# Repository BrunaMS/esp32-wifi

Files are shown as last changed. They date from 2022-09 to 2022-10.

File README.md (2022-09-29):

# esp32-wifi
In this project I'm using ESP32 with ESP-IDF framework to implement an Wi-Fi connection, allowing to download 500kb files from a device at least 100m away

## Firmware
### Environment
To develop and build this firmware I'm using VSCode and it's extensions. The main extension required to build it is platformIO but others like git extension can be used to help with version control and gitflow. 

### Task routine
To work with different services/threads I chose to use the  

## Hardware
For now, I'm using KiCad 6.0 to create schematics and PCB for this project. During the development was necessary to download components from external sources. These are:
- Example I
- Example II

### Components 
For this project some circuits are necessary, mainly to guarantee battery charging and to protect other modules and the microcontroller from damages.
- BQ - Battery control
- USB Protection circuit
- Crystal
- Voltage regulator
- Wi-Fi antenna performance
- GPIOs

### Microcontroller
The chosen microcontroller for this application was the ESP32-WROOM, developed to work with IoT and wireless in general, making wireless communication protocols easier to develop and use.

### Routing
The general rules for the routing process were:
1. Consider one manufacturer to define the correct pcb specifications (hole size, clearance, board thickness, impedance control, etc)
2. Always consider grounding rules
3. Avoid interference from power lines
4. Avoid keep high-speed signals close to other signals

## TODO 

|Area | Type |Description|
|-----|---|---|
|Firmware|Feature|Move device mode selector from kconfig to serial/nvs memory
|Firmware|Feature|Develop some type of interface to be used when it is in receiver mode
|Firmware|Fix| Convert components into real components (submodules in git), making possible the use in other projects
|Firmware|Fix| Organize the different "layers" of the project (e.g. components, common, task, main), creating uncoupled classes/libraries/functions
|Firmware|Docs| Explain function in header (.h file) of each component(brief, params, return) using Doxygen 
|Hardware|Test|Check if with built-in antenna can reach 100m of distance between devices or if its necessary to use another one |

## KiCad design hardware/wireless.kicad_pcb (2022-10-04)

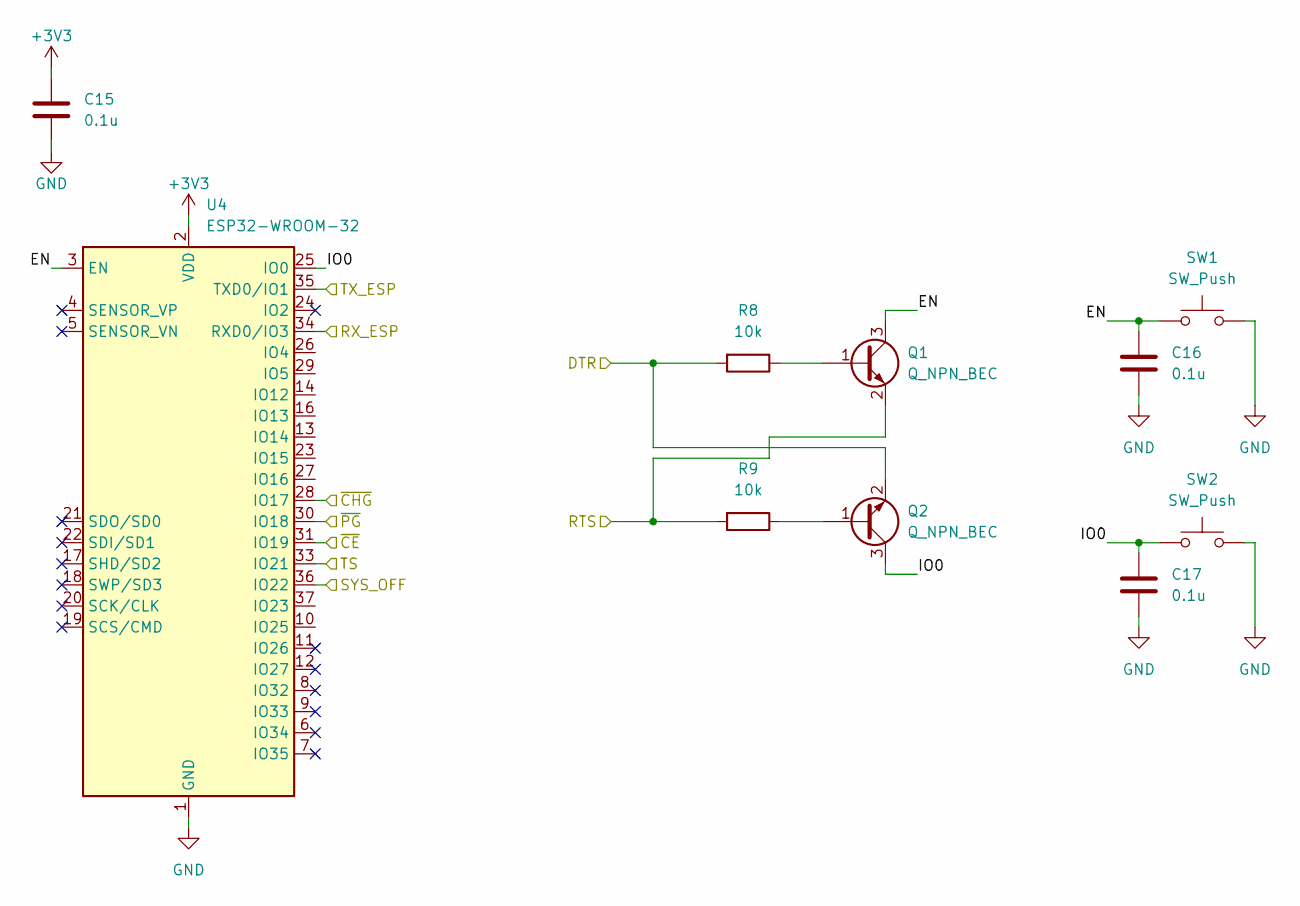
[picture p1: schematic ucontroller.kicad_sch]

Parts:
C15, C16, C17: 0.1u; C_0402_1005Metric
Q1, Q2: Q_NPN_BEC; SOT-323_SC-70
R8, R9: 10k; R_0402_1005Metric
SW1, SW2: SW_Push; SW_SPST_B3S-1000
U4: ESP32-WROOM-32

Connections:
+3V3: C15.1, U4.2 (VDD); also elsewhere on the board
/power_supply/SYS_OFF: U4.36 (IO22); also elsewhere on the board
/power_supply/TS: U4.33 (IO21); also elsewhere on the board
/power_supply/~CE: U4.31 (IO19); also elsewhere on the board
/power_supply/~CHG: U4.28 (IO17); also elsewhere on the board
/power_supply/~PG: U4.30 (IO18); also elsewhere on the board
/ucontroller/DTR: Q2.2 (E), R8.2; also elsewhere on the board
/ucontroller/EN: C16.1, Q1.3 (C), SW1.1, U4.3 (EN)
/ucontroller/IO0: C17.1, Q2.3 (C), SW2.1, U4.25 (IO0)
/ucontroller/RTS: Q1.2 (E), R9.2; also elsewhere on the board
/ucontroller/RX_ESP: U4.34 (RXD0/IO3); also elsewhere on the board
/ucontroller/TX_ESP: U4.35 (TXD0/IO1); also elsewhere on the board
GND: C15.2, C16.2, C17.2, SW1.2, SW2.2, U4.1 (GND), U4.15 (GND), U4.38 (GND), U4.39 (GND); also elsewhere on the board
unnamed: Q1.1 (B), R8.1
unnamed: Q2.1 (B), R9.1

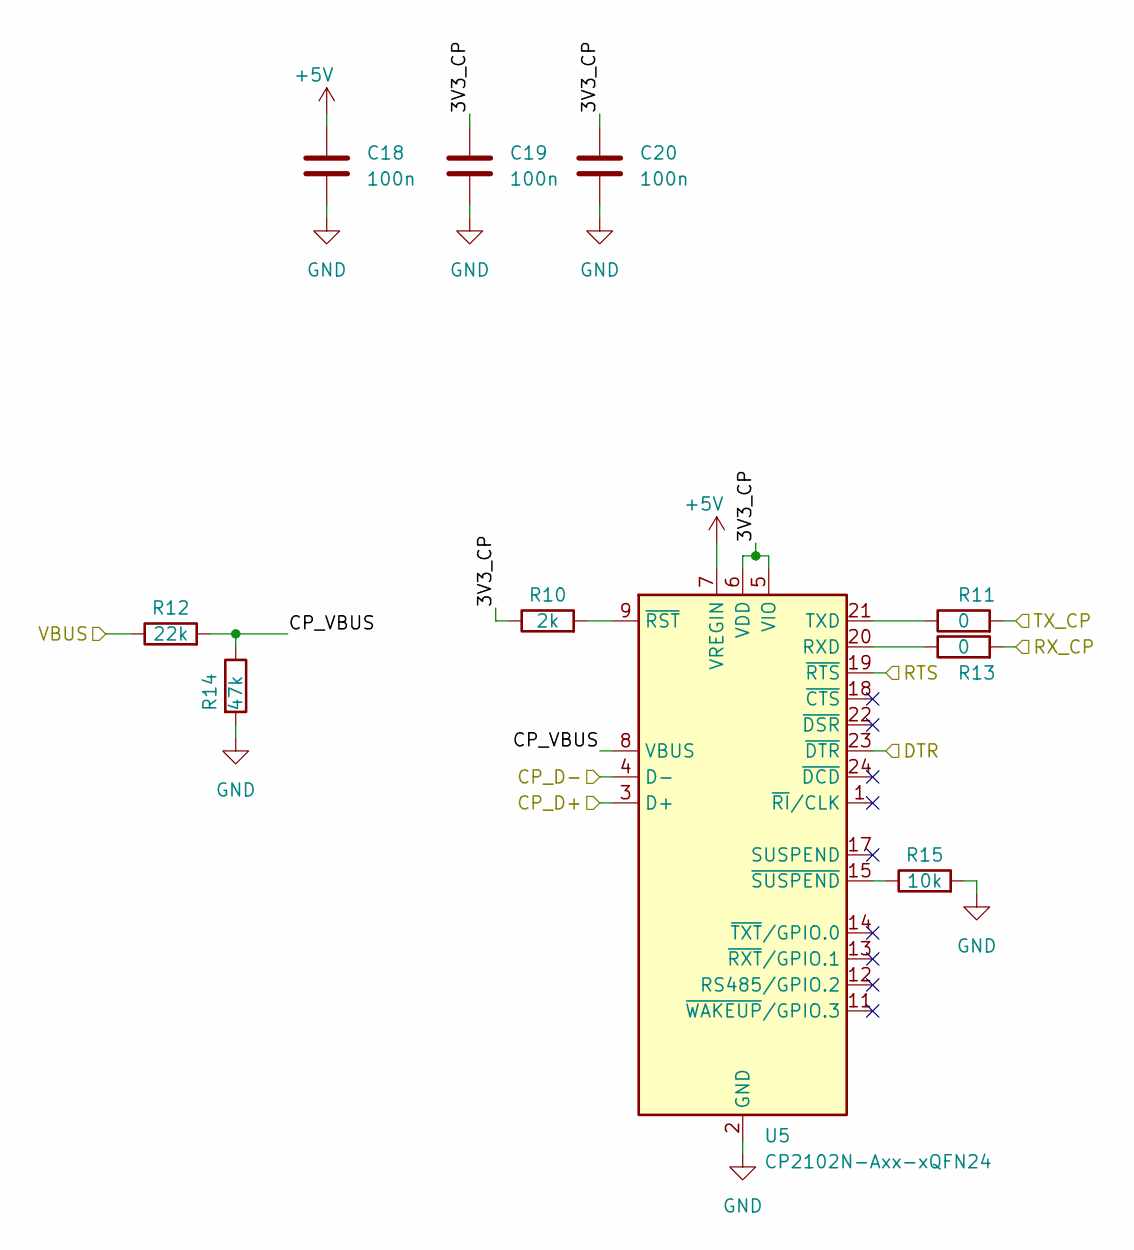
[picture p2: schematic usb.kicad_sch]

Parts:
C18, C19, C20: 100n; C_0402_1005Metric
R10: 2k; R_0402_1005Metric
R11, R13: 0; R_0402_1005Metric
R12: 22k; R_0402_1005Metric
R14: 47k; R_0402_1005Metric
R15: 10k; R_0402_1005Metric
U5: CP2102N-Axx-xQFN24; QFN-24-1EP_4x4mm_P0.5mm_EP2.6x2.6mm

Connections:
+5V: C18.1, R12.1, U5.7 (VREGIN); also elsewhere on the board
/power_supply/USB_D+: U5.3 (D+); also elsewhere on the board
/power_supply/USB_D-: U5.4 (D-); also elsewhere on the board
/ucontroller/DTR: U5.23 (~DTR); also elsewhere on the board
/ucontroller/RTS: U5.19 (~RTS); also elsewhere on the board
/ucontroller/RX_ESP: R11.2; also elsewhere on the board
/ucontroller/TX_ESP: R13.2; also elsewhere on the board
/usb/3V3_CP: C19.1, C20.1, R10.1, U5.5 (VIO), U5.6 (VDD)
/usb/CP_VBUS: R12.2, R14.1, U5.8 (VBUS)
GND: C18.2, C19.2, C20.2, R14.2, R15.2, U5.2 (GND), U5.25 (GND); also elsewhere on the board
unnamed: R10.2, U5.9 (~RST)
unnamed: R11.1, U5.21 (TXD)
unnamed: R13.1, U5.20 (RXD)
unnamed: R15.1, U5.15 (~SUSPEND)

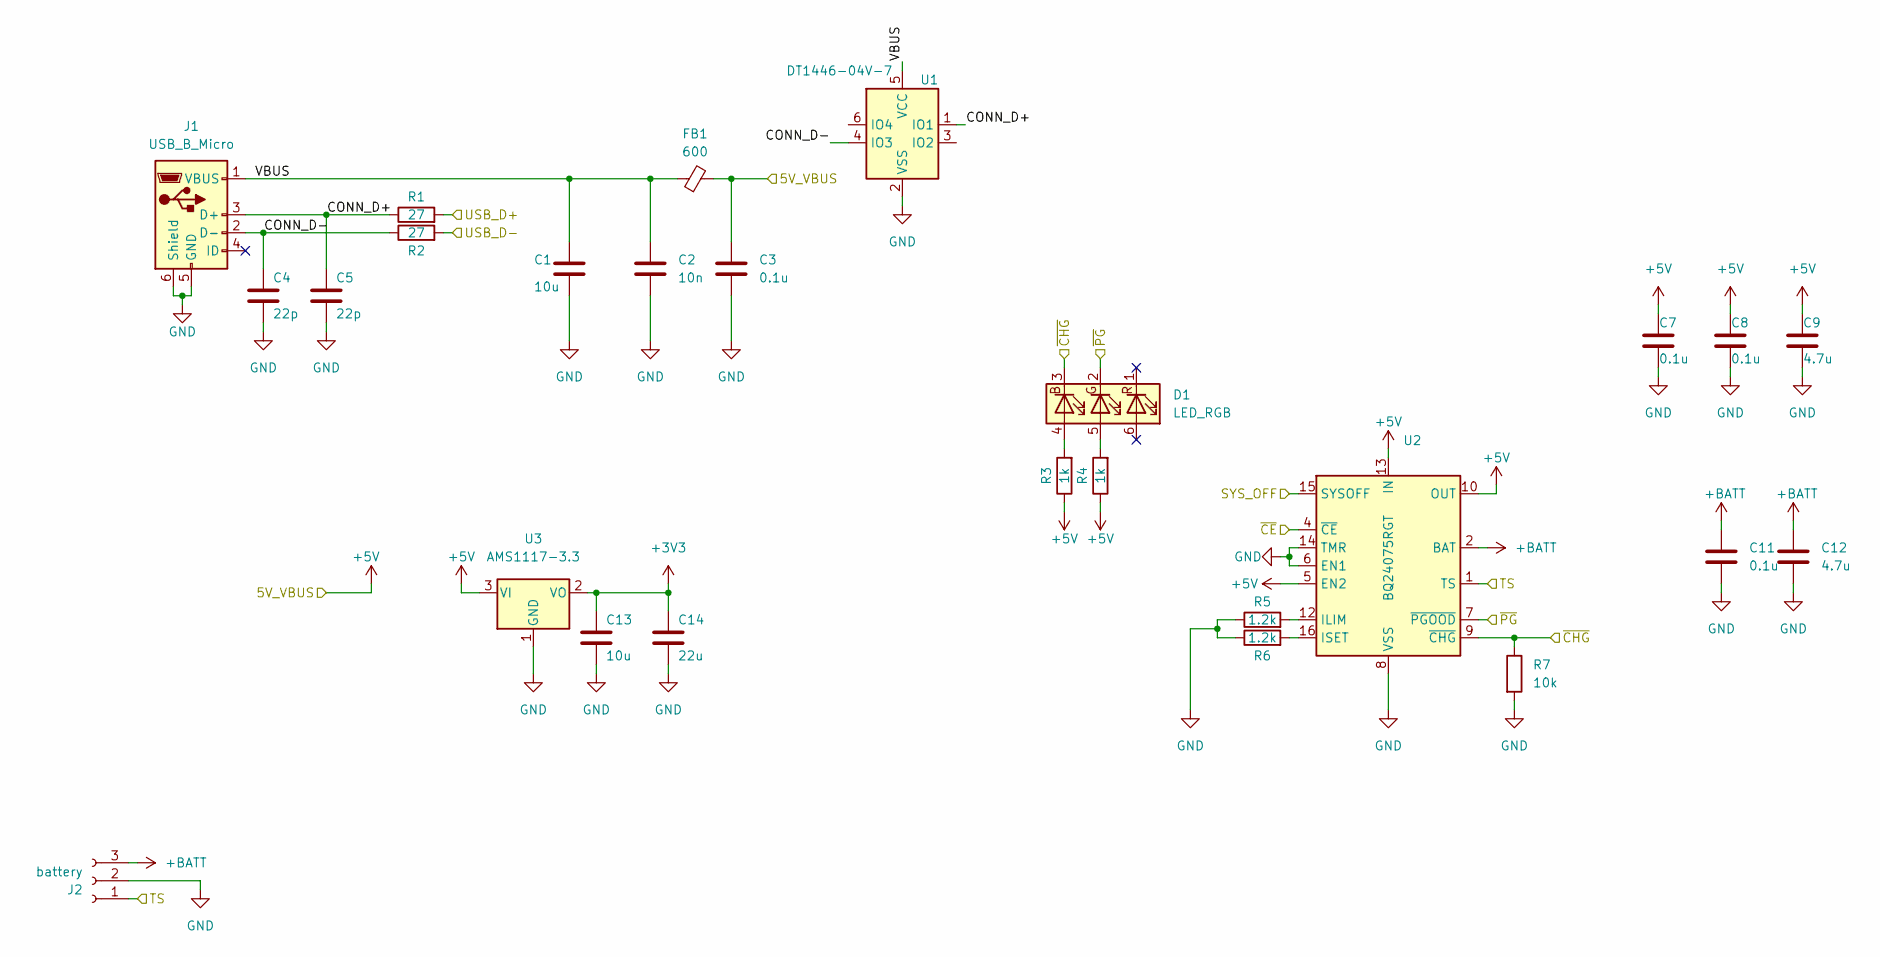
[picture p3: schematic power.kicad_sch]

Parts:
C1, C13: 10u; C_0603_1608Metric
C2: 10n; C_0402_1005Metric
C3, C7, C8, C11: 0.1u; C_0402_1005Metric
C4, C5: 22p; C_0402_1005Metric
C9, C12: 4.7u; C_0603_1608Metric
C14: 22u; C_0603_1608Metric
D1: LED_RGB; LED_RGB_5050-6
FB1: 600; L_0603_1608Metric
J1: USB_B_Micro; USB_Micro-B_Amphenol_10103594-0001LF_Horizontal
J2: battery; FanPinHeader_1x03_P2.54mm_Vertical
R1, R2: 27; R_0603_1608Metric
R3, R4: 1k; R_0402_1005Metric
R5, R6: 1.2k; R_0402_1005Metric
R7: 10k; R_0402_1005Metric
U1: DT1446-04V-7; SOT95P280X120-6N
U2: BQ24075RGT; VQFN-16-1EP_3x3mm_P0.5mm_EP1.6x1.6mm
U3: AMS1117-3.3; SOT-223-3_TabPin2

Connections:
+3V3: C13.1, C14.1, U3.2 (VO); also elsewhere on the board
+5V: C3.1, C7.1, C8.1, C9.1, FB1.2, R3.1, R4.1, U2.5 (EN2), U2.10 (OUT), U2.11 (OUT), U2.13 (IN), U3.3 (VI); also elsewhere on the board
+BATT: C11.1, C12.1, J2.3, U2.2 (BAT), U2.3 (BAT)
/power_supply/CONN_D+: C5.1, J1.3 (D+), R1.1, U1.1 (IO1)
/power_supply/CONN_D-: C4.1, J1.2 (D-), R2.1, U1.4 (IO3)
/power_supply/SYS_OFF: U2.15 (SYSOFF); also elsewhere on the board
/power_supply/TS: J2.1, U2.1 (TS); also elsewhere on the board
/power_supply/USB_D+: R1.2; also elsewhere on the board
/power_supply/USB_D-: R2.2; also elsewhere on the board
/power_supply/VBUS: C1.1, C2.1, FB1.1, J1.1 (VBUS), U1.5 (VCC)
/power_supply/~CE: U2.4 (~CE); also elsewhere on the board
/power_supply/~CHG: D1.3 (BK), R7.1, U2.9 (~CHG); also elsewhere on the board
/power_supply/~PG: D1.2 (GK), U2.7 (~PGOOD); also elsewhere on the board
GND: C1.2, C2.2, C3.2, C4.2, C5.2, C7.2, C8.2, C9.2, C11.2, C12.2, C13.2, C14.2, J1.5 (GND), J1.6 (Shield), J2.2, R5.1, R6.1, R7.2, U1.2 (VSS), U2.6 (EN1), U2.8 (VSS), U2.14 (TMR), U2.17 (VSS), U3.1 (GND); also elsewhere on the board
unnamed: D1.4 (BA), R3.2
unnamed: D1.5 (GA), R4.2
unnamed: R5.2, U2.12 (ILIM)
unnamed: R6.2, U2.16 (ISET)

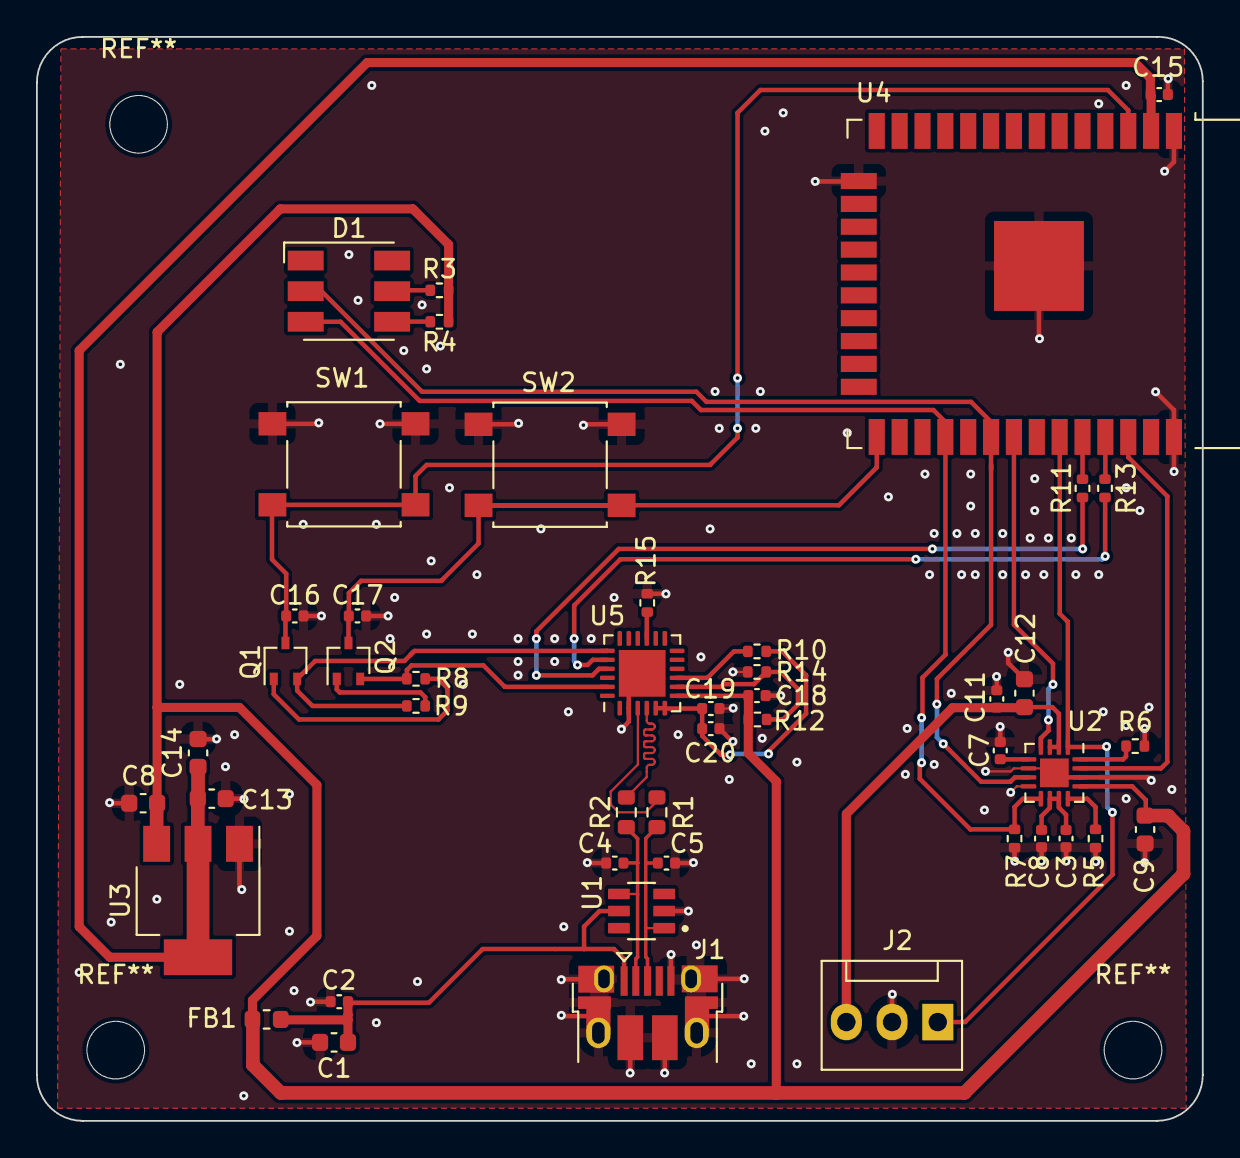
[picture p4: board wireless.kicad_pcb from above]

Board: 2 copper layers, 64.8 x 60.2 mm, 47 parts (0 on the bottom side), 32 nets.

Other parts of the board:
C8#2: 0.1u; C_0402_1005Metric

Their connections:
+5V: C8#2.1; also elsewhere on the board
GND: C8#2.2; also elsewhere on the board

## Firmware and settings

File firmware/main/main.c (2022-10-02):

#include "esp_log.h"

#include "freertos/FreeRTOS.h"
#include "freertos/event_groups.h"

#include "filesystem.h"
#include "wifiTaskHandler.h"

void app_main(void)
{
    initFilesystem();
    TaskHandle_t wifiHandle = NULL;
#ifdef CONFIG_WIFI_DEVICE_MODE_TRANSMITTER
    xTaskCreate(wifiServiceTransmitter, "wifiService", 30000, NULL, configMAX_PRIORITIES - 1, &wifiHandle);
#else
#ifdef CONFIG_WIFI_DEVICE_MODE_RECEIVER
    xTaskCreate(wifiServiceReceiver, "wifiService", 30000, NULL, configMAX_PRIORITIES - 1, &wifiHandle);
#endif
#endif
    vTaskDelay(pdMS_TO_TICKS(5));
    vTaskDelete(NULL);
}

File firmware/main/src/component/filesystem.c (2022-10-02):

/* SPIFFS filesystem example.
   This example code is in the Public Domain (or CC0 licensed, at your option.)
   Unless required by applicable law or agreed to in writing, this
   software is distributed on an "AS IS" BASIS, WITHOUT WARRANTIES OR
   CONDITIONS OF ANY KIND, either express or implied.
*/

#include <stdio.h>
#include <string.h>
#include <sys/unistd.h>
#include <sys/stat.h>
#include "esp_err.h"
#include "esp_log.h"
#include "esp_spiffs.h"
#include "filesystem.h"

#define TAG "filesystem"
#define SPIFFS_PATH "/storage"
#define MAX_FILE_NAME 64

bool deleteFile(char *filename){
    char path[MAX_FILE_NAME] = "";
    snprintf(path,  MAX_FILE_NAME, "%s/%s", SPIFFS_PATH, filename);
    return (remove(path) == 0);
}

bool exists(char *filename){
    struct stat buffer;   
    char path[MAX_FILE_NAME] = "";
    
    snprintf(path,  MAX_FILE_NAME, "%s/%s", SPIFFS_PATH, filename);
    return (stat(path, &buffer) == 0);
}

int writeFile(char* filename, char* content, bool append){
    char path[MAX_FILE_NAME] = "";
    FILE* f = NULL;
    
    snprintf(path, MAX_FILE_NAME, "%s/%s", SPIFFS_PATH, filename);
    f = fopen(path, append?"a":"w");
    
    ESP_LOGI(TAG, "Writing on file");
    if (f == NULL) {
        ESP_LOGE(TAG, "Failed to open file for writing");
        return -1;
    }
    fprintf(f, content);
    fclose(f);
    return 0; 
}


bool getNextFilePart(char* filename, char* buffer, int bufferSize, int* len){
    bool eof = false;
    static FILE *f = NULL;
    char path[MAX_FILE_NAME] = "";
    
    if(f == NULL){
        ESP_LOGW(TAG, "File '%s' is not open yet. Doing that now.", filename);
        snprintf(path, MAX_FILE_NAME, "%s/%s", SPIFFS_PATH, filename);
        f = fopen(path, "r");
    }
    char c = '\0';
    int size = 0;
    while(!eof && (size < bufferSize)){
        c = fgetc(f);
        eof = feof(f);
        if(!eof){
            buffer[size] = c;
            size++;
        }
    }
    *len = size;
    if(eof){
        fclose(f);
        f = NULL;
        return false;
    }
    buffer[size] = '\0';
    return true;
}

int readFile(char* filename, char* buffer, int bufferSize){
    char path[MAX_FILE_NAME] = "";
    FILE* f = NULL;
    
    snprintf(path, MAX_FILE_NAME, "%s/%s", SPIFFS_PATH, filename);
    f = fopen(path, "r");
    
    ESP_LOGI(TAG, "Reading file");
    if (f == NULL) {
        ESP_LOGE(TAG, "Failed to open file for reading");
        return -1;
    }

    char c = 'a';
    int size = 0;
    while(!feof(f) && (size < bufferSize)){
        c = fgetc(f);
        if(!feof(f)){
            buffer[size] = c;
            size++;
        }
    }
    if(!feof(f)){
        ESP_LOGW(TAG, "Reached buffer size before eof");
    }

    fclose(f);
    ESP_LOGI(TAG, "Read from file: '%s'", buffer);
    return size;
}

void initFilesystem(void)
{
    ESP_LOGI(TAG, "Initializing SPIFFS");

    esp_vfs_spiffs_conf_t conf = {
      .base_path = SPIFFS_PATH,
      .partition_label = NULL,
      .max_files = 5,
      .format_if_mount_failed = true
    };

    // Use settings defined above to initialize and mount SPIFFS filesystem.
    // Note: esp_vfs_spiffs_register is an all-in-one convenience function.
    esp_err_t ret = esp_vfs_spiffs_register(&conf);

    if (ret != ESP_OK) {
        if (ret == ESP_FAIL) {
            ESP_LOGE(TAG, "Failed to mount or format filesystem");
        } else if (ret == ESP_ERR_NOT_FOUND) {
            ESP_LOGE(TAG, "Failed to find SPIFFS partition");
        } else {
            ESP_LOGE(TAG, "Failed to initialize SPIFFS (%s)", esp_err_to_name(ret));
        }
        return;
    }

#ifdef CONFIG_SPIFFS_CHECK_ON_START
    ESP_LOGI(TAG, "Performing SPIFFS_check().");
    ret = esp_spiffs_check(conf.partition_label);
    if (ret != ESP_OK) {
        ESP_LOGE(TAG, "SPIFFS_check() failed (%s)", esp_err_to_name(ret));
        return;
    } else {
        ESP_LOGI(TAG, "SPIFFS_check() successful");
    }
#endif

    size_t total = 0, used = 0;
    ret = esp_spiffs_info(conf.partition_label, &total, &used);
    if (ret != ESP_OK) {
        ESP_LOGE(TAG, "Failed to get SPIFFS partition information (%s). Formatting...", esp_err_to_name(ret));
        esp_spiffs_format(conf.partition_label);
        return;
    } else {
        ESP_LOGI(TAG, "Partition size: total: %d, used: %d", total, used);
    }


    // Check consistency of reported partiton size info.
    if (used > total) {
        ESP_LOGW(TAG, "Number of used bytes cannot be larger than total. Performing SPIFFS_check().");
        ret = esp_spiffs_check(conf.partition_label);
        // Could be also used to mend broken files, to clean unreferenced pages, etc.
        // More info at https://github.com/pellepl/spiffs/wiki/FAQ#powerlosses-contd-when-should-i-run-spiffs_check
        if (ret != ESP_OK) {
            ESP_LOGE(TAG, "SPIFFS_check() failed (%s)", esp_err_to_name(ret));
            return;
        } else {
            ESP_LOGI(TAG, "SPIFFS_check() successful");
        }
    }
}

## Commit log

2022-09-29 Create receiver module firmware
    [wireless.kicad_pcb, wireless.kicad_sch]
2022-09-29 Send file content using http and create table partition for spiffs usage
    [table_partitions.csv]
2022-10-03 Start hardware development
    [power.kicad_sch, ucontroller.kicad_sch, usb.kicad_sch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]
2022-10-04 finish hw development and generate gerber files
    [power.kicad_sch, ucontroller.kicad_sch, usb.kicad_sch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]
